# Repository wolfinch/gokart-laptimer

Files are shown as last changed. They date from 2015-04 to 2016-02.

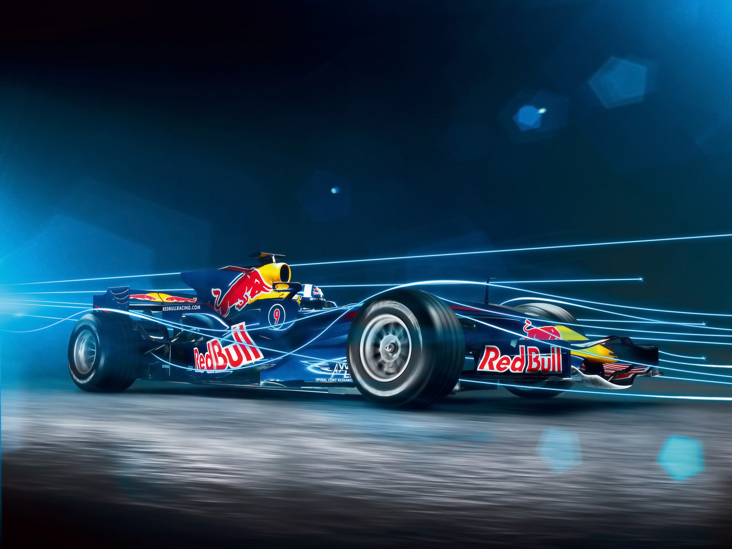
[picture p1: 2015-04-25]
gokart-web/f1-bg.jpg

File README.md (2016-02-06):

#Gokart-LapTimer-iMproved (GLTiM) 1.0
---------
The GLTiM is built on top of the gokart-laptimer which uses IR beacon and Raspbery Pi as detector/Receiver. 
The GLT improved provides many more features than the previous version plus a more streamlined web interface.

1. Two way RF communication using Nordic NRF24L01+ RF chip between Control center and detector
2. Detector Supports Magnetic Strip as well as IR beacon
3. Detector is in Kart. Allows feedback for the driver (not implemented)
4. Raspberry Pi as control Center 

# gokart-laptimer 0.1
Open hardware-software project to setup a go kart lap timer and counter with IR as the trigger beacon. 

1. NEC pulse width IR protocol is used as the beacon protocol. 
2. Raspberry-Pi based controller.
3. php based GUI.

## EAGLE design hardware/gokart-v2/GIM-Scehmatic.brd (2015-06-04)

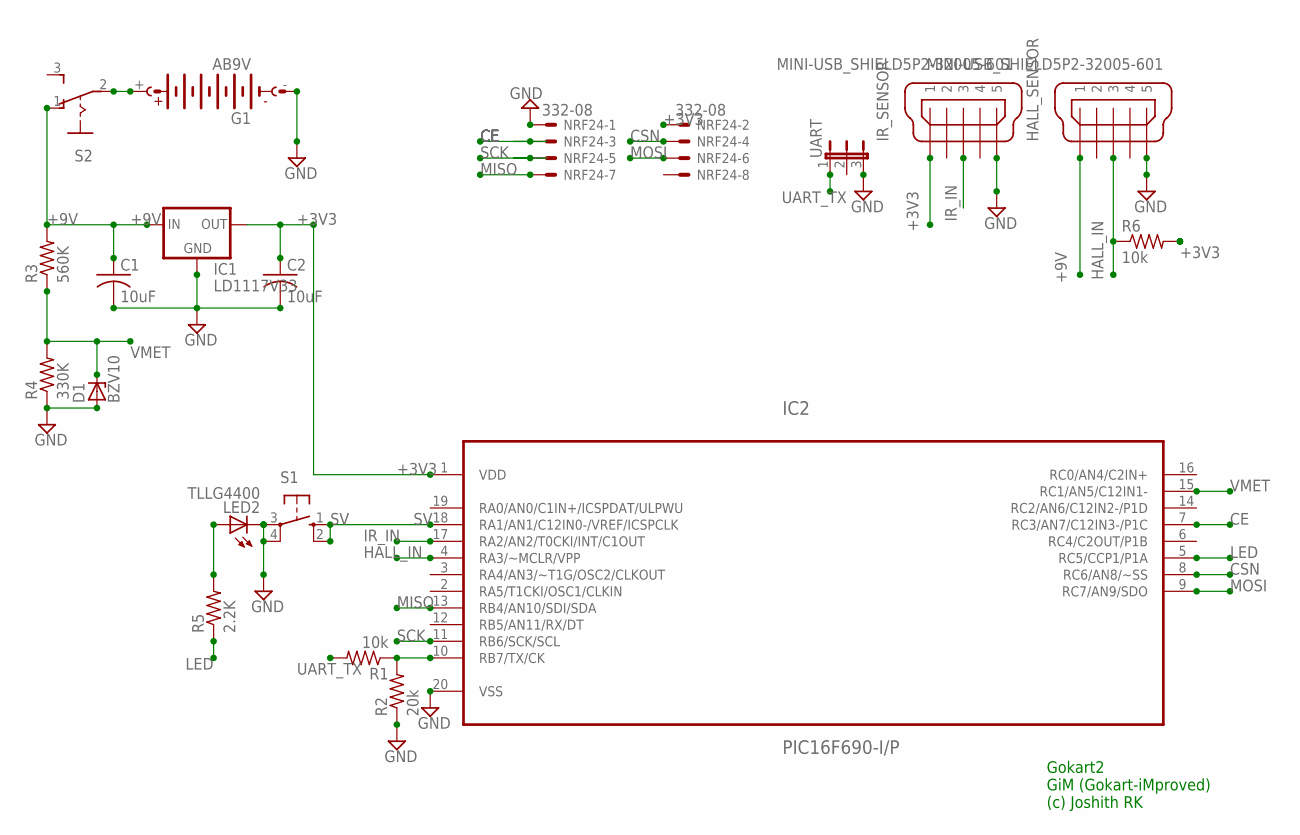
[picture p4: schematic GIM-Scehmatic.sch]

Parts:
C1, C2: 10uF; C025-040X050
D1: BZV10; DO34Z7
G1: AB9V
HALL_SENSOR: MINI-USB_SHIELD5P2-32005-601; 32005-601
IC1: LD1117V33
IC2: PIC16F690-I/P; DIP254P762X533-20
IR_SENSOR: MINI-USB_SHIELD5P2-32005-601; 32005-601
LED2: TLLG4400; LED3MM
NRF24: 332-08
R1, R6: 10k; 0204/7
R2: 20k; 0204/7
R3: 560K; 0204/7
R4: 330K; 0204/7
R5: 2.2K; 0204/7
S1: 10-XX; B3F-10XX
S2: M251
UART: JP2E; JP2

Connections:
+3V3: C2.1, IC1.OUT, IC2.1 (VDD), IR_SENSOR.1, NRF24.2, R6.2
+9V: C1.1, HALL_SENSOR.1, IC1.IN, R3.2, S2.1 (O)
CE: IC2.7 (RC3/AN7/C12IN3-/P1C), NRF24.3
CSN: IC2.8 (RC6/AN8/~SS), NRF24.4
GND: C1.2, C2.2, D1.A, G1.-, HALL_SENSOR.5, IC1.GND, IC2.20 (VSS), IR_SENSOR.5, LED2.K (C), NRF24.1, R2.1, R4.1, S1.3, S1.4 (P1), UART.3
HALL_IN: HALL_SENSOR.3, IC2.4 (RA3/~MCLR/VPP), R6.1
IR_IN: IC2.17 (RA2/AN2/T0CKI/INT/C1OUT), IR_SENSOR.3
LED: IC2.5 (RC5/CCP1/P1A), R5.1
MISO: IC2.13 (RB4/AN10/SDI/SDA), NRF24.7
MOSI: IC2.9 (RC7/AN9/SDO), NRF24.6
unnamed: IC2.10 (RB7/TX/CK), R1.1, R2.2
unnamed: G1.+, S2.2
unnamed: LED2.A, R5.2
SCK: IC2.11 (RB6/SCK/SCL), NRF24.5
SV: IC2.18 (RA1/AN1/C12IN0-/VREF/ICSPCLK), S1.1 (S), S1.2 (S1)
UART_TX: R1.2, UART.1
VMET: D1.C, IC2.15 (RC1/AN5/C12IN1-), R3.1, R4.2

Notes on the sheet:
Gokart2 GiM (Gokart-iMproved) (c) Joshith RK

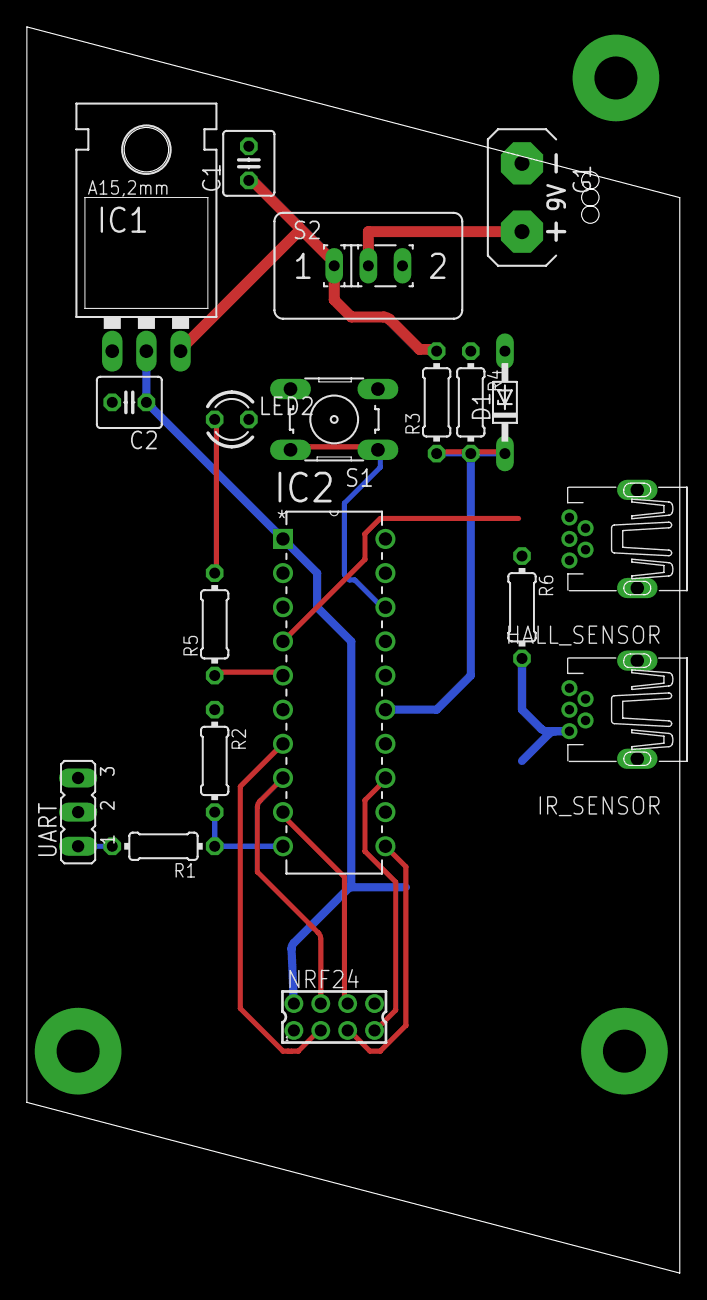
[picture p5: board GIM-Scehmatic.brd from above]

Board: 2 copper layers, 48.6 x 92.7 mm, 19 parts (0 on the bottom side), 17 nets.

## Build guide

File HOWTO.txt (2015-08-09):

Install:
+++++++++

1. Install easyphp-Devserver.exe
2. Once installed, open easyphp by clicking the taskbar easyphp icon. Verify the apache is started
3. Right click the easyphp icon (in the step-2), on the menu go submenu 'configure'->'apache'. 
	3a) it will open a notepad file, search for "Listen 127.0.0.1:80". change it to "Listen *:80"
4. Copy all the files in 'gokart-web' folder to "C:\Program Files (x86)\EasyPHP-DevServer-14.1VC11\data\localweb\" folder
5. Done and ready to go. 

Usage:
=======

To test:
A) Test local server functionality
1. open browser
2. type 'localhost/single_session.php' -> Verify it gives the command center page
3. On another tab, open 'localhost/results.php' -> Verify it gives the results page.

B) Test the server is reachable in other machines (PC/laptop)

1. On another system (laptop, desktop) on the same network, 
	try the above steps by giving 'IP' of Server (the machine with easyphp installed) 
	in place of localhost and verify above

C) Test the transponder/Detector functionality

1. Plug in the raspberry pi to power source and ethernet cable
2. Verify the raspberry pi comes up and picks up IP
3. Find the raspberry Pi IP and put the IP in the "server IP" field in the command center page.
4. Turn on the transmitter and verify the device id, this can be changed later
5. From the command center page, enter a "name" of driver (optional) and click start button
6. Verify the start button turns red and no error is given.
7. Move the transmitter to the sensor proximity with min 10 Sec (Min lap time, configurable) and verify the laptimes in Results page 

# Ips of systems in the network can be found using android app "fing" with the phone connected to same network

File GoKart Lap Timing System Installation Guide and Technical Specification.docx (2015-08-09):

GoKart Lap Timing System Installation Guide and Technical Specification

# Introduction

This document discuss about the Gokart Lap Timing system and technical specifications and installation guidelines.

Kart Timer system is designed to use in kart tracks. The system can identify up to 250 different karts and measure their lap time with one millisecond accuracy.

The Kart Timing system is equipped to be used with Infrared beacon based Race tracks and Magnetic strip based tracks.

# 1. System components

## 1.1. Required components

    1.1.1. Computer with timing software
    1.1.2. Stationary Infrared Beacon
    1.1.3. Magnets
    1.1.4. Receiver module with WifI or Ethernet connectivity (off Kart controll station)
    1.1.5. Transmitter modules (in kart control station)
    1.1.6. IR Sensor
    1.1.7. Magnetic Strip Sensor
  1.2. Optional Components
    1.1.1. Camera Module for Receiver

The IR and Magnetic sensors a detachable from the transmitter (in kart control station) and are provided with 1.5m long flexible cables for providing flexibility of sensor positioning in the kart.

The in kart control station is powered with 6 AA batteries (not supplied), which should last long enough in ideal use cases, however is replaceable by the user. The kart control center is equipped with two power switches, which enables to turn off the module completely or turn off the magnetic sensor alone to reduce power consumption and to provide longer battery life. The in kart control center is also equipped with a battery monitor. So the Admin is informed with battery level of the transmitter.

The Receiver (off kart control center) and the IR beacon needs to be placed off track in the suitable positions as shown in fig-2. The Receiver and IR beacon are powered with regular micro-USB based power adapters (not supplied).

The receiver module is the main control center, which receives the lap time information from the karts and consolidates and provides the necessary information for the computer software.

The in kart transmitter and receiver uses a 2.4 GHz RF radio communication method for exchanging data. The transmitter provides detection data to the receiver along with a kart-id of the transmitter. The id could be programmed in the in kart transmitter module. Up to 255 unique IDs could be programmed on the transmitter, making it usable with 255 karts running together.

The receiver is also provided with an option to use a camera module, to enable automatically taking photos of the karts while completing the lap and the photos if enabled would be displayed on the scorecard software.

The receiver must be connected to the computer through the WiFi or using the Ethernet cables with the ports provided. Ethernet is preferred, as it does not require additional configuration of the receiver module.

1. Installation directions

The fig-1 below shows the block diagrom of the lap-timing system with all the components connected.

Power

Computer

IR Beacon

Reciever

IR

Radio

Magnetic Strip

Transmitter

Magnetic Sensor

IR Sensor

Fig-1

IR LEDs

Magnetic strip

IR Beacon

Receiver

to power Adaptor

track

To Computer

Fig-2

Fig-2 Above shows the Installation of IR Beacon and Recievers off track.

## Magnetic strip installation

One magnetic strip should be installed into the track.

### Magnetic strip installation using 150x19x10 ferrite magnets

- Cut a 20x20 mm groove across the track
- Lay a 20mm wide steel sheet along the groove
- Lay the magnets on the steel sheet. Rotate the magnets until the red side is visible of every magnet in the strip.
- WARNING! The magnets shall be laid with homogeneous polarization! It means, that only one pole of the magnets are visible from upwards. The north pole of our magnets are marked with red painting. The strip will be homogeneous, if the red side is visible of every magnet after the installation.
- The magnets are pushing each other with homogeneous polarization, but the steel sheet can join them. Duct tape can be used instead of steel sheet also.
- Check the polarization of the strip. It is homogeneous, if the red side is visible of every magnet. You can check the polarization with a piece of magnet also. Hold the magnet in you hand, and move it along the strip. If the polarization is homogeneous, the magnet in you hand does not rotate.

Next picture shows the WRONG magnetic strip installation (side view). The South (blue) and North (red) poles are pulling each other. The installation is easy, but the resultant magnetic field is inhomogeneous! It results in magnetic field degradation, and loss of timing system reliability.

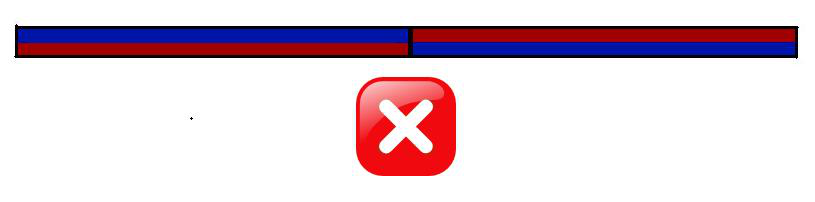
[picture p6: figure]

Next picture shows the GOOD magnetic strip installation. The South (blue) poles and the North (red) poles are pushing each other. The installation is not easy; the steel sheet under the magnets (grey) helps the installation greatly. Steel sheet can be used on the top of the strip also, without magnetic field degradation. The resultant magnetic field is homogeneous.

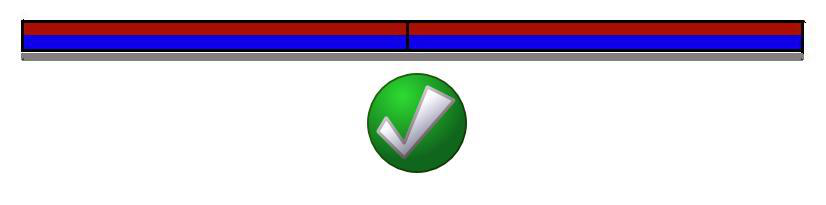
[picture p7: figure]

## Receiver module installation

- Fix the receiver module next to the magnetic strip, 3 meters above ground. The receiver should be maximum 8 meters from any point of the magnetic strip.
- Connect the receiver module with the computer using the ethernet cable/wifi dongle.
- Connect the reciever module to the appropriate micro-usb power adaptor

## Transmitter installation

- Drill installation holes on the floor of each kart. Be careful when choosing the place of the transmitter.
- Fix the transmitter on the floor of each kart.
- Drill holes for fixing the magnetic and IR sensors.
- Magnetic sensors should be placed such a way that it is at maximum 6cm height from the magnetic strip
- IR sensors should be placed with sensor facing straight up towards the IR beacon installed.
- Connect the sensor cables to the transmitter modules.

Care should be taken to connect each sensor only at their dedicated port.

## Software installation

TBD: TODO:

# 2. Stability and reliability

The lap timing system is a stable and reliable system when correctly installed. It means that every lap of every running kart shall be identified, and the lap time accuracy shall be 1 millisecond. If you are experiencing problems with system stability and reliability, please check the following list.

## 1.1.1. Magnetic strip recognition

Ensure that your magnetic strip is correctly installed. Check the homogeneity of the magnetic field. If you are using magnetic strip from other supplier, check if the magnets are strong enough.

Ensure that the distance between the transmitter and the magnetic strip is no more than 6 cm when passing the magnetic strip. Be careful with kerbs if your strip is not in straight, since it can lift up the kart.

Ensure that the kart speed is between 5 and 100 km/h when passing the magnetic strip

Ensure that no disturbing magnetic fields (e.g. engine) are in 50 cm distance of the transmitter. Be careful with the engine of the other karts, it can be a problem during close races.

## 1.1.2. Radio transmit

Ensure that the distance between transmitter and receiver is no more than 8 m when passing the magnetic strip.

Ensure that no disturbing objects are between transmitter and receiver when passing the magnetic strip.

Ensure that the receiver is at least 2 m above ground. The optimal position is 3 m above magnetic strip, in center position.

## 1.1.3. Computer and communication

Do not use longer cables than 100 m between receiver and computer.

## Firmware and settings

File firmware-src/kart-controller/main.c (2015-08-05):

/* 
 * File:   main.c
 * Author: Joshith
 *
 * Created on 23 March, 2015, 11:13 AM
 */

// 'C' source line config statements
#include "user.h"
#include "nrf24.h"
#include "util/xprintf.h"
#include <xc.h>
#include <stdbool.h>

/* Initialize EEPROM */
__EEPROM_DATA(0x02, 0x00, 0x00, 0x00, 0x00, 0x00, 0x00, 0x00);
/* Dev_id*/
extern volatile uint8_t devId;
extern volatile uint8_t cfgMode;
// extern volatile uint8_t ShouldSend;
extern volatile uint8_t ir_cmd_valid;
extern volatile uint8_t ir_cur_code;
extern volatile uint8_t hall_detect;
extern volatile uint16_t jiffies;

extern volatile gim_timeval ir_cur_hit;
extern volatile gim_timeval hall_cur_hit;

extern volatile uint8_t ir_lap_count;
extern volatile uint8_t hall_lap_count;

//uint8_t     hall_send_success = true;
extern volatile kart_data_t data[MAX_PAYLOAD_COUNT];                       // Payload list to send
extern volatile int8_t      data_count;
extern volatile uint8_t      data_rx_slot;
extern volatile uint8_t      data_next_rx_slot;
volatile uint8_t     battery_level = 0xff;
uint8_t              gim_seed;

/* TMR1 Tick time = 8uS 
 * Gives .5242Sec TMR1 Overflow time (Interrupt Time - clock resolution)
 * if we inc jiffies every int, gives an error of 1/40 Sec.
 * jiffies stores timeval in .5Sec resolution. 
 * TMR1H Gives 2mS resolution tick (TMRH Preset with value 0xB which to be considered). 
 * so, Time in Sec:mS = jiffies/2:TMR1H*2
 */
inline uint16_t epoch (void) {
    return jiffies; ///2;  Lets do the costly operations from Serverside.
}

void nrf_print_details() {
    uint8_t status = nrf24_getStatus();
    
    xprintf("NRF24+ STATUS\t\t = 0x%02x RX_DR=%x TX_DS=%x MAX_RT=%x RX_P_NO=%x TX_FULL=%x\r\n",
           status,
           (status & (1 << RX_DR))?1:0,
           (status & (1 << TX_DS))?1:0,
           (status & (1 << MAX_RT))?1:0,
           ((status >> RX_P_NO) & 0b111),
           (status & (1 << TX_FULL))?1:0
          );
    
    xprintf("Data Rate\t = 0x%x\r\n", (getDataRate()));
    xprintf("CRC Length\t = 0x%x\r\n", (getCRCLength()));
    xprintf("PA Power\t = 0x%x\r\n", getPALevel()); 
     
}

void nrf24_send_detect_data(void ) {
    kart_data_t rx_data;
    uint8_t retry;
    uint8_t d_cnt = 0;
    
    xprintf("%s: ENTER data_count:%d\r\n", "nrf24_send_detect_data", data_count);
    
    while (data_ready()) {
        if (!is_data_valid(d_cnt)) {
            if (data_next_rx_slot == data_rx_slot) {
                data_next_rx_slot = d_cnt;
            }
            if (++d_cnt >= MAX_PAYLOAD_COUNT) {
                nrf24_powerDown();
                return;
            } else {
                continue;
            }
        }
        /* Automatically goes to TX mode */
        xprintf("bat_level: 0x%x sec: %d mS:%d type:0x%x code: 0x%x lap_cnt:%d\r\n", data[d_cnt].battery_level, data[d_cnt].time.sec,
                data[d_cnt].time.m_sec, data[d_cnt].detect_type, data[d_cnt].detect_code, data[d_cnt].lap_count);

        data[d_cnt].seed = gim_seed;
        nrf24_send((uint8_t *) (&data[d_cnt]));
        while (nrf24_isSending());
        /* Make analysis on last tranmission attempt */
        if (nrf24_lastMessageStatus() == NRF24_MESSAGE_LOST) {
            xprintf("Message is lost ...\r\n");
        }
        
        /* Retranmission count indicates the tranmission quality */
        xprintf("Retranmission count: 0x%x\r\n", nrf24_retransmissionCount());

        /* Even if the data send show failure, it could be an ack miss. 
         * If we get a response back for the previous sent, we are ok
         */
        nrf24_powerUpRx();
        retry = 20;
        gim_seed++;
        do {
            if (nrf24_dataReady()) {
                nrf24_getData((uint8_t *) & rx_data);
                xprintf("Rx: devId:0x%x retry: 0x%d\r\n", rx_data.dev_id, retry);
                if (rx_data.dev_id != devId) {
                    /* Error, wrong response recvd, ignore, resend*/
                    break;
                }
                data_count--;
                /* unset the data slot, */
                data_unset(d_cnt);
                if (data_next_rx_slot == data_rx_slot) {
                    data_next_rx_slot = d_cnt;
                }
                if (!data_ready()) {
                    nrf24_powerDown();
                    return;
                }
                break;
            }
            retry--;
            __delay_ms(5); // wait and retry
        } while (retry);
        
        if (++d_cnt >= MAX_PAYLOAD_COUNT) {
            nrf24_powerDown();            
            return;
        }
    }
 }
    
void
handle_ir_cmd (void) {
    static gim_timeval ir_first_hit, ir_last_hit;
    //static uint8_t     is_ir_first_hit     = true;
    static uint8_t     is_ir_lap_valid     = true;

    if (ir_cmd_valid) {
        //xprintf("va%d", ir_state_pos);
        ir_cmd_valid = false;
        if (is_ir_lap_valid || ir_last_hit.sec + 4 < ir_cur_hit.sec) {
            // This is the first hit of a new lap
            ir_last_hit = ir_first_hit = ir_cur_hit;
            is_ir_lap_valid = false;           // Marking first IR hit since we are operational
        } else { //if the signal comes within 2Sec, advance the window
            ir_last_hit = ir_cur_hit;
        }
    } else if ((ir_last_hit.sec + 4 < jiffies) && !is_ir_lap_valid) {
        // Last IR detect was >2 Sec ago. Calculate the lap-time and send now

        xprintf("*** Valid IR lap!!***\r\n");
        is_ir_lap_valid = true;
        
        data[data_rx_slot].time.sec = ir_first_hit.sec/2 + ir_cur_hit.sec/2 + 
                (ir_first_hit.sec%2 | ir_cur_hit.sec%2); // Take avg. (adjust reminder =>.5+.5 = .5)
        data[data_rx_slot].time.m_sec = ir_first_hit.m_sec / 2 + ir_cur_hit.m_sec / 2; // Take avg.
                
        /* Create send data and insert */
        battery_level = read_battery_level();
        data[data_rx_slot].battery_level = battery_level;
        data[data_rx_slot].dev_id = devId;
        data[data_rx_slot].detect_type = IR;
        data[data_rx_slot].detect_code = ir_cur_code;
        data[data_rx_slot].lap_count = ir_lap_count;
        data_set (data_rx_slot);
        data_rx_slot = data_next_rx_slot;
        data_count++; //new data to send
        ir_lap_count++; // Set lap_count wraparound = 63

        return;
    }
}
#if 0
void cont_wave_test (void) {
    
    nrf24_powerDown();
    nrf24_configRegister(RF_SETUP, (1 << CONT_WAVE) | (1 << PLL_LOCK) | (0 << RF_DR_HIGH) | (0 << RF_DR_LOW) | ((0x03) << RF_PWR));
    nrf24_configRegister(RF_CH, 10);
    
    nrf24_powerUpTx();
    
    CE = 1;

}
void carrier_detect( void) {    
    uint8_t i = 40;
    nrf24_powerUpRx();

    while (i--) {
        // Select this channel
        nrf24_configRegister(RF_CH, i);

        // Start listening
        __delay_us(128);
        //radio.stopListening();

        // Did we get a carrier?
        if (testRPD())
            ++value[i];
        //stopListening();
    }
    
    for (i=0; i<40; i++) {
        xprintf("%x", (value[i]&0xF));
    }
    xprintf("\n\r");
}

void ping_out (void) {
    uint8_t val = 10;
    // Select this channel
    nrf24_configRegister(RF_CH, 5);
  //  nrf24_powerUpTx();
    nrf24_send (&val);
}

void rx_test (void) {
    kart_data_t rx_data;
    uint8_t     rcount =0;
    
    nrf24_powerUpRx();
    while (1) {
        while(!nrf24_dataReady());
        if(nrf24_dataReady()) {
            gim_seed++;
            nrf24_getData((uint8_t *) & rx_data);
            xprintf("Rx: devId:0x%x lap_cnt: %d\r\n", rx_data.dev_id, rx_data.lap_count);
            rx_data.seed = gim_seed;

            nrf24_send((uint8_t *) (&rx_data));
            /* Wait for transmission to end */
            xprintf("nrf24_isSending?\r\n");
            while (nrf24_isSending()) {
                print_observe_tx();
            };

            /* Make analysis on last tranmission attempt */
            rcount = nrf24_lastMessageStatus();

            if (rcount == NRF24_TRANSMISSON_OK) {
                xprintf("Tranmission went OK\r\n");
            } else if (rcount == NRF24_MESSAGE_LOST) {
                xprintf("Message is lost ...\r\n");
                return;
            }
            /* Retranmission count indicates the tranmission quality */
            rcount = nrf24_retransmissionCount();
            xprintf("Retranmission count: 0x%x\r\n", rcount);
            nrf24_powerUpRx();
        }
        __delay_ms(60);
    }
}
#endif

void main() {
    uint8_t i = 0;
    
    /* Read config */
    devId = eeprom_read(0x00);
    
    /* Initialize everything */
    InitApp();
    xprintf("InitApp OK\r\n");
    
    battery_level = read_battery_level();

    xprintf("Dev Id 0x%x batLevel:0x%x\r\n", devId, battery_level);

    blinkLed(devId);
    xprintf("Init Complete\r\n");
    nrf_print_details();

//    cont_wave_test();
//    rx_test();
//#if 0
	while(1)
    {        
        handle_ir_cmd();
        
        /* if there is a signal hit, current data slot must be used up, get next slot*/
        if (data_next_rx_slot == data_rx_slot) {
            for (i = 0; i < MAX_PAYLOAD_COUNT; i++) {
                if(i == data_rx_slot)
                    continue;
                if (!is_data_valid(i)) {
                    data_next_rx_slot = i;
                    break;
                }
            }
            if (i == MAX_PAYLOAD_COUNT) {
                if(data_next_rx_slot == MAX_PAYLOAD_COUNT-1) {
                    data_next_rx_slot = 0; //If no slots are available, select (remove) the oldest data
                } else {
                    data_next_rx_slot++;
                }
            }
            //xprintf("Rx_slot:%d next_slot:%d \r\n", data_rx_slot, data_next_rx_slot);
        }
        
        if (hall_detect) { //Hall detected
            hall_detect = 0;
            xprintf("*** Hall Signal Received!!*** d_cnt: %d bmap: 0b%b\r\n", data_count, data_valid_bitmap);
        }

        if (data_ready()) {
            nrf24_send_detect_data();
        }

       // if (ShouldSend) {
         //   ShouldSend = 0;
            //         nrf24_send_detect_data();
        //}

        /* If no activity for time more than 2mins, Let's power down flush-out the date (if any) and Sleep now.*/
        if ((ir_cur_hit.sec + 1200 < jiffies) && (hall_cur_hit.sec + 1200 < jiffies )) {
            xprintf("--- Entering SLEEP mode!!---\r\n");
            data_q_flush();
            nrf24_powerDown();
            jiffies = 0; // Reset the jiffies
            SLEEP ();
            battery_level = read_battery_level();
        }
        __delay_ms(60);
    }
//#endif
}

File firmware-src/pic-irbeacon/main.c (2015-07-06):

/* 
 * File:   main.c
 * Author: Joshith
 *
 * Created on 23 March, 2015, 11:13 AM
 */

//__CONFIG(FOSC_INTOSCIO & WDTE_OFF & PWRTE_OFF & MCLRE_OFF & CP_OFF & IOSCFS_8MHZ & BOREN_NSLEEP);


// PIC16F684 Configuration Bit Settings

// 'C' source line config statements
#include "user.h"
#include <xc.h>


/* Initialize EEPROM */
__EEPROM_DATA(0x03, 0x00, 0x00, 0x00, 0x00, 0x00, 0x00, 0x00);
/* Dev_id*/
extern volatile unsigned short devId;
extern volatile unsigned short cfgMode;
//extern volatile unsigned short comp;


void main()
{
    /* Initialize everything */
    InitApp();
    
    /* Read config */
    devId = eeprom_read(0x00);
    
    //comp = (devId << 4);
    //comp = (comp)|((~devId)&0x03);
    blinkLed(devId+1);
    

	while(1)
	{
        /* Send IR frame with programmed deviceID and default data key*/
        /* if not in config mode */
        if(devId && !cfgMode) {
            sendFrame(devId, DATA_KEY_1);
        }
        //__delay_ms(2);
    }
}

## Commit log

2015-04-25 bug fix: button id stripping needed
2015-06-04 Added files for gokart-controller
    This adds the functionality with intelligent in-kart controller.
    Support magnetic strip and IR beacon on the track. Sends the detection
    data to the rPi controller off-track reliably through RF radio
2015-06-04 added hardware related files
    gokart-controller schematic and board files. Created using eagle
    [GIM-Scehmatic.brd, GIM-Scehmatic.sch, GIM-Scehmatic1.brd]
2015-06-05 IR and hall sensor optimizations
2015-06-06 Fixed IR interrupt timing
    [main.c]
2015-06-08 multisection support, bugfixes, optimizations
    [main.c, nrf24.c, user.h]
2015-06-16 web related changes to support multiple sensors etc.
2015-06-18 web interface changes for battery level and lap counts on control panel
2015-06-21 Major design changes in timer handling across firmware, software and web.
    With this changes, time stamp is stored, which is adjusted across
    wraparound. Firmware sends Lap number and a seed to protect loosing lap
    count in case a lap is missed.
    [main.c, user.c, user.h]
2015-06-22 Lap number wraparound logic fix
    [main.c]
2015-07-06 Final set of changes in IR Beacon for the PCB
